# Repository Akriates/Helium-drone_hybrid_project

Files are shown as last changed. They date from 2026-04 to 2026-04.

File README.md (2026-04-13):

# Helium-drone_hybrid_project

An internship project to develop a working prototype of a helium drone hybrid

---

## Project Overview

This project focuses on developing a hybrid aerial system designed for **sustained surveillance**. By combining the natural lift of a helium balloon with the controlled movement of a drone, the system aims to remain airborne for extended periods while still being able to navigate its environment.

The helium component provides passive lift, reducing the energy required to stay airborne and enabling longer operation compared to traditional drones. Motorized propulsion allows the system to reposition and maintain control when needed, while an onboard camera supports real-time observation.

This project primarily serves as an **experimental prototype** to evaluate the feasibility and effectiveness of such a hybrid system. It explores how well a helium-assisted platform can perform in practical scenarios, identifying both its advantages and limitations.

Overall, the work lays the groundwork for future improvements in long-duration aerial monitoring, system stability, and autonomous capabilities.

---

## System Architecture

The system is built around a distributed architecture where each component is responsible for a specific function:

* **Raspberry Pi 5** – Main processing unit, handles high-level control, ROS 2 communication, and future vision processing
* **Arduino Uno** – Controls servos and processes IMU data
* **Pixhawk 2.4.8** – Handles motor control and low-level flight stabilization

This separation allows the system to remain modular, making it easier to debug, upgrade, and expand in future iterations.

---

## Hardware

### Mechanical Structure

The parts within this folder correspond to the **final tested prototype** used during system validation. This includes the full mechanical structure that supports the propulsion system, electronics, and camera assembly.

While this design was functional, it should be considered an **early iteration**. A redesign is recommended to improve:

* Wiring integration and routing
* Structural strength and weight distribution
* Ease of assembly and maintenance
* Mounting solutions for electronics and sensors

### Full Assembly

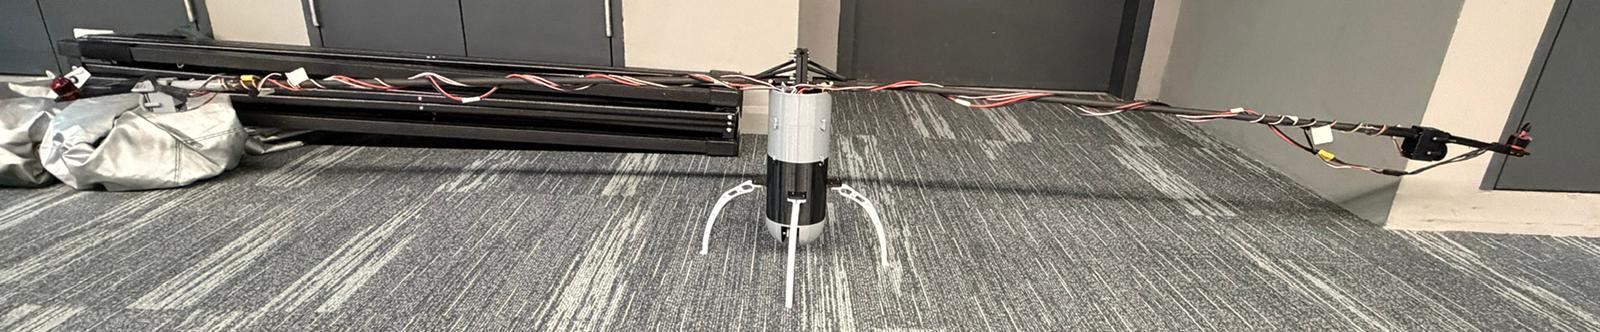
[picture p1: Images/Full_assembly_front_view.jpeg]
Full Assembly

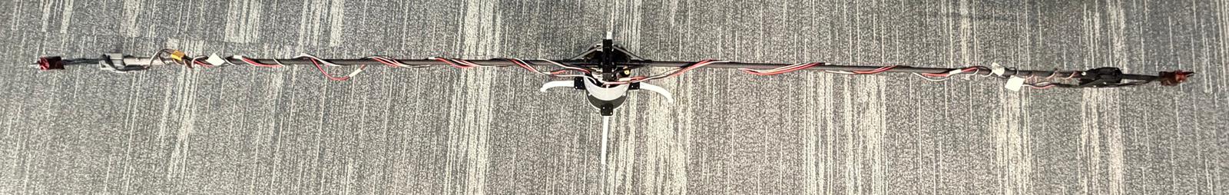
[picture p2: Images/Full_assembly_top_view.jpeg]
Full Assembly

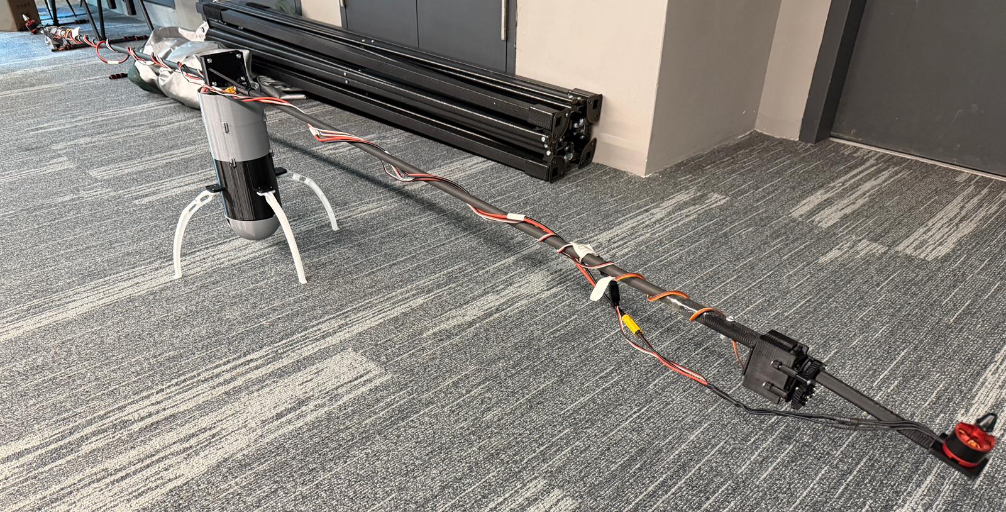
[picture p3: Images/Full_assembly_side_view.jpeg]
Full Assembly


---

### Electronics

#### Components Used

**Control Systems**

* Raspberry Pi 5
* Arduino Uno
* Pixhawk 2.4.8

**Actuation**

* MG996R Servos
* A2212 Brushless Motors
* Electronic Speed Controllers (ESCs)

**Sensing**

* MPU9250 IMU

**Wiring and Power**

* Jumper wires (male-to-male, male-to-female)
* Servo extension cables
* Custom XT60 power cables (~1m)
* Custom power distribution wiring
* Additional connection wires

#### Wiring Layout

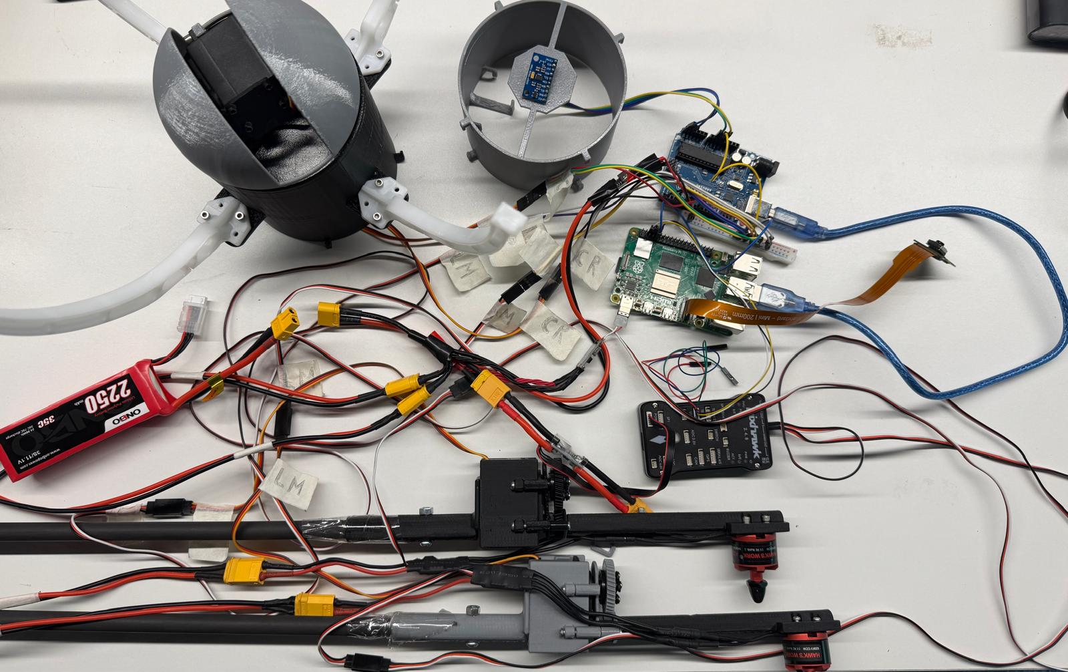
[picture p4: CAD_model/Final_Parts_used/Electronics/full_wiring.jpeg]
Full Wiring

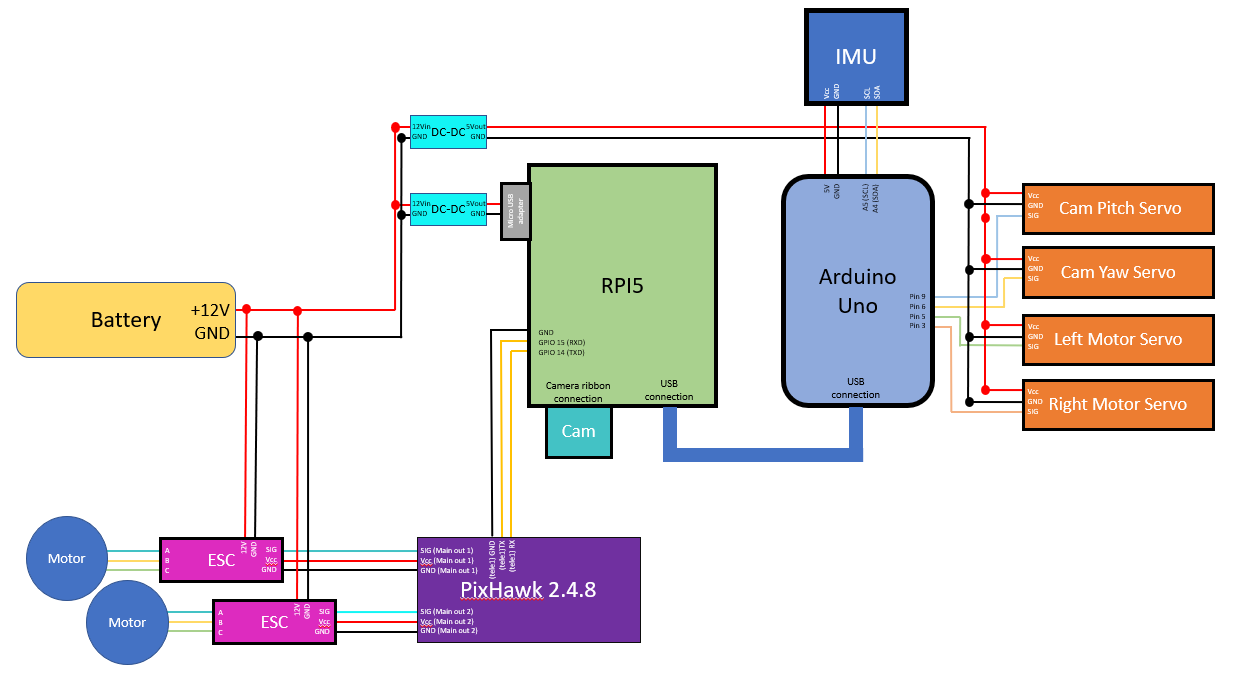
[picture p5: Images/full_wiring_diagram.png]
Full Wiring


#### Design Considerations

* Avoid powering servos directly from microcontroller 5V rails
* Improve cable management and routing
* Replace temporary jumper wires with secure connectors
* Use dedicated power distribution solutions
* Integrate wiring paths into the mechanical design

---

## Software

The system software is primarily built on **ROS 2**, enabling communication between different components of the system.

### Key Features

* Serial communication between Raspberry Pi and Arduino for servo control and IMU data
* MAVLink communication between Raspberry Pi and Pixhawk for motor control
* Teleoperation nodes for movement and camera control
* Real-time sensor feedback integration

The software is designed to be modular, allowing future integration of computer vision and autonomous control systems.

---

## Results and Testing

The prototype successfully demonstrated:

* Basic controlled movement using motor tilt mechanisms
* Stable communication between Raspberry Pi, Arduino, and Pixhawk
* Real-time IMU data acquisition
* Functional camera positioning system

The system validated the core concept of combining helium lift with drone propulsion for extended operation.

---

## Limitations

* Limited stability in dynamic environments
* No true position hold (IMU-only stabilization)
* Wiring complexity affects reliability
* Mechanical structure not optimized for long-term use

---

## Future Work

Future improvements will focus on:

* Improved mechanical design with integrated wiring channels
* Advanced stabilization algorithms
* Integration of additional sensors (e.g. GPS, barometer)
* Computer vision for tracking and autonomous navigation
* More efficient power distribution system

---

## Acknowledgements

This project was developed as part of an internship program, serving as a proof-of-concept for hybrid aerial surveillance systems.

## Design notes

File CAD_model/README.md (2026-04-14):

## CAD Models

This folder contains the different model versions developed throughout the project. These models represent multiple design iterations created from repeated testing and refinement.

- **Full Model (Version 1)**  
  This is the first and most complete design, created as a reverse-engineered approximation of an existing helium drone product. It represents the best attempt at replicating a functional system based on available observations and understanding.

- **Final Parts Configuration**  
  This version focuses primarily on the **electronics packaging and integration**, ensuring that all components could be physically mounted and operated together for a self-contained test setup.

- **Version 2 (Conceptual Design)**  
  This is a theoretical redesign developed after insights gained from building and testing the initial prototype. It reflects improvements in structure, layout, and overall system considerations.

Overall, these models document the design evolution of the project, from initial replication to more informed and refined concepts.

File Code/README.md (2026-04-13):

# System Overview

This system is built around a Raspberry Pi 5 acting as the main controller. It interfaces with an Arduino Uno over USB serial for servo control and IMU data, and a Pixhawk 2.4.8 over UART (MAVLink) for motor control.

The Raspberry Pi sends commands to control motor tilt and camera servos, receives real-time orientation data (roll, pitch, yaw), and manages motor arming and throttle through the Pixhawk.

ROS 2 is used to structure the system, with nodes handling serial communication, MAVLink control, and data publishing. This setup provides a foundation for teleoperation and future extensions such as computer vision and autonomous control.

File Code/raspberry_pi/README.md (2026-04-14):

# Raspberry Pi Control System (Arduino + Pixhawk + ROS 2)

This module runs on the **Raspberry Pi 5** and acts as the central control computer for the system. It manages communication with both the Arduino Uno (USB serial) for servo control and IMU data, and the Pixhawk 2.4.8 (UART via MAVLink) for motor control.

The Raspberry Pi is responsible for sending commands, receiving sensor data, and running ROS 2 nodes that coordinate the entire system.

---

## Core Responsibilities

The Raspberry Pi handles:

- Sending servo commands to the Arduino over USB serial
- Receiving and parsing IMU data from the Arduino
- Communicating with Pixhawk using MAVLink (pymavlink)
- Arming/disarming motors and sending RC override signals
- Running ROS 2 nodes for control and communication
- Acting as the platform for:
  - Teleoperation
  - Sensor processing
  - Future autonomy (CV, navigation)

---

## Hardware Connections

### Arduino (USB Serial)
- Device: /dev/ttyACM0 (may vary)
- Baud rate: 115200

### Pixhawk (UART)
- Device: /dev/ttyAMA0
- Baud rate: 57600
- Connection:
  - Pixhawk TX → Pi RX
  - Pixhawk RX → Pi TX
  - Shared GND

---

## Arduino Serial Communication

Commands are newline-terminated strings:

COMMAND,arg1,arg2,...

### Commands

Drive servos:
DRV,right,left

Camera servos:
CAM,rot,pitch

All servos:
ALL,right,left,rot,pitch

Ping:
PING

### Expected Responses

- ACK,DRV
- ACK,CAM
- ACK,ALL
- PONG
- ERR,BAD_DRV
- ERR,BAD_CAM
- ERR,BAD_ALL
- ERR,UNKNOWN_CMD

---

## IMU Data Stream

The Arduino continuously sends IMU data at ~20 Hz:

IMU,ax,ay,az,gx,gy,gz,mx,my,mz,roll,pitch,yaw

### Field Description

- ax, ay, az → acceleration (g)
- gx, gy, gz → angular velocity (deg/s)
- mx, my, mz → magnetometer (calibrated)
- roll, pitch, yaw → orientation (degrees)

---

## Python Serial Example

```python
import serial

ser = serial.Serial('/dev/ttyACM0', 115200, timeout=1)

ser.write(b'DRV,45,135\n')

while True:
    line = ser.readline().decode().strip()
    if line:
        print(line)
```

---

## Pixhawk Communication (MAVLink)

```python
from pymavlink import mavutil

master = mavutil.mavlink_connection('/dev/ttyAMA0', baud=57600)
master.wait_heartbeat()
print("Connected to Pixhawk")
```

---

## Motor Control

Arm motors:

```python
master.arducopter_arm()
master.motors_armed_wait()
```

Disarm motors:

```python
master.arducopter_disarm()
```

---

## RC Override Example

```python
master.mav.rc_channels_override_send(
    master.target_system,
    master.target_component,
    1500, 1500, 1500, 1500,
    0, 0, 0, 0
)
```

Notes:
- Channel 3 = throttle
- 1000 = minimum
- 1500 = neutral
- 2000 = maximum

---

## ROS 2 Integration (Jazzy)

### Topics

Subscribed:
- /servo_drive_cmd → [right, left]
- /servo_camera_cmd → [rot, pitch]

Published:
- /arduino_imu → sensor_msgs/msg/Imu

---

## Node Responsibilities

Serial Bridge Node:
- Opens /dev/ttyACM0
- Sends DRV / CAM commands
- Reads IMU data
- Publishes IMU messages

MAVLink Node:
- Connects to Pixhawk
- Arms/disarms motors
- Sends RC override commands

---

## Launch File Example

```python
from launch import LaunchDescription
from launch_ros.actions import Node

def generate_launch_description():
    return LaunchDescription([
        Node(
            package='helium_arduino_interface',
            executable='serial_bridge',
            name='arduino_serial'
        ),
        Node(
            package='helium_mav_control',
            executable='mav_motor_controller',
            name='pixhawk_control'
        ),
    ])
```

---

## Teleoperation Example

Drive mapping:

- w → forward
- s → backward
- a → left
- d → right
- x → neutral

Camera:
- rotation centered at 90°
- pitch centered at 45°
- incremental control

---

## Startup Behavior

When the Arduino is ready, it sends:

READY

The Raspberry Pi should wait for this before sending commands.

---

## Main Runtime Behavior

The Raspberry Pi continuously:

1. Reads serial input from Arduino
2. Parses IMU and ACK messages
3. Sends servo commands when needed
4. Sends MAVLink commands to Pixhawk
5. Publishes data to ROS 2 topics

---

## Important Notes

- Do not run MAVProxy and ROS node on /dev/ttyAMA0 at the same time
- Only one process should access each serial port
- Always send newline (\n) with commands
- Disarm is the safest way to stop motors
- Ensure correct UART wiring (TX ↔ RX)

---

## Limitations

- No automatic reconnect
- No command retry system
- No synchronization between IMU and Pixhawk data
- No position hold (IMU-only system)
- No Pi-side failsafe

---

## Summary

The Raspberry Pi acts as the central control layer, interfacing with both the Arduino and Pixhawk. It sends actuator commands, receives IMU data, and runs ROS 2 nodes that enable system control, integration, and future expansion.

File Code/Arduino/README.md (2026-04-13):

# Arduino Servo + IMU Firmware (Arduino Uno)

This firmware runs on an **Arduino Uno** and provides a combined interface for **servo control** and **MPU9250 IMU sensing**. It exposes a simple **USB serial protocol** so an external system (Raspberry Pi) can send servo commands while receiving real-time IMU data. The code handles low-level hardware control, sensor fusion (roll, pitch, yaw), and continuous telemetry streaming.

The Arduino is connected to the Raspberry Pi via **USB serial (115200 baud)**.

---

## Features

- Control of **4 servos**
  - Right motor tilt
  - Left motor tilt
  - Camera rotation (pan)
  - Camera pitch (tilt)
- Reads **MPU9250 IMU (Accel + Gyro + Magnetometer)**
- Computes **roll, pitch, yaw** using a complementary filter
- Performs **magnetometer calibration at startup**
- Streams IMU data at **20 Hz**
- Supports a simple **serial command protocol**
- Uses **safe startup servo positions**

---

## Hardware Configuration

### Servos
| Function | Pin |
|---|-----|
| Right Motor Tilt | 3 |
| Left Motor Tilt | 5 |
| Camera Rotation | 6 |
| Camera Pitch | 9 |

### IMU
- Sensor: **MPU9250 + AK8963 magnetometer**
- Interface: **I2C (Wire library)**
- Addresses:
  - MPU9250: `0x68`
  - Magnetometer: `0x0C`

---

## Servo Behaviour

- Default startup positions:
  - Right motor: `90°`
  - Left motor: `90°`
  - Camera rotation: `90°`
  - Camera pitch: `45°`

- Angle limits:
  - General servos: `0° – 180°`
  - Camera pitch: `0° – 90°` (hardware constrained)

- Custom calibrated pulse widths:
  ```cpp
  servoRightMotor.attach(pin, 450, 2600);
  servoLeftMotor.attach(pin, 500, 2550);
  servoCamRot.attach(pin, 500, 2500);
  servoCamPitch.attach(pin, 500, 2500);

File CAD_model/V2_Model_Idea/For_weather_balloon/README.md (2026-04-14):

This version will be for working with the weather balloon for future testing before investing in a full custom frame and balloon

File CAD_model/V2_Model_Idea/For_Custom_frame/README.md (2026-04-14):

This version is just the new frame design based on what I learnt and inspiration after designing the first version

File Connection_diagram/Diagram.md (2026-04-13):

The full wiring diagram as a drawing:

Full Wiring

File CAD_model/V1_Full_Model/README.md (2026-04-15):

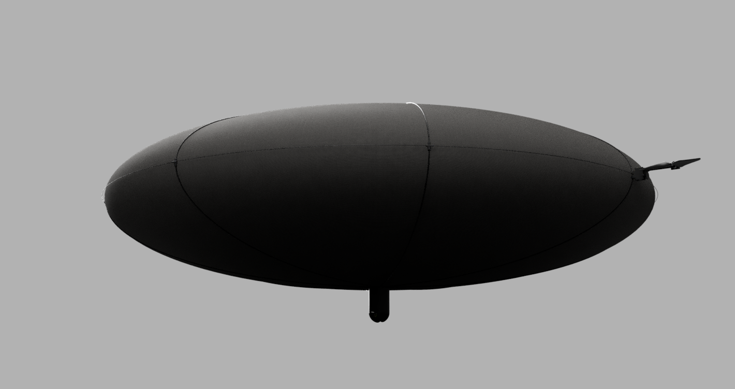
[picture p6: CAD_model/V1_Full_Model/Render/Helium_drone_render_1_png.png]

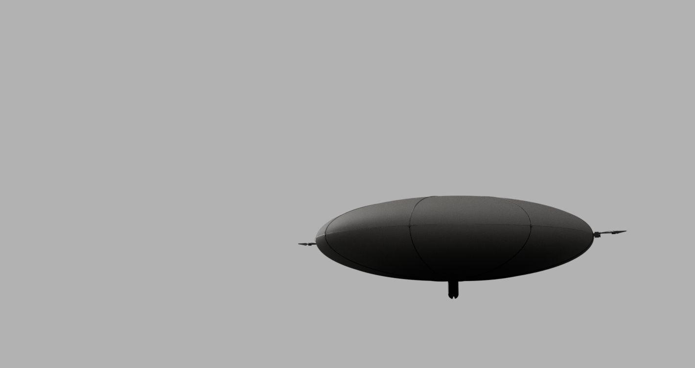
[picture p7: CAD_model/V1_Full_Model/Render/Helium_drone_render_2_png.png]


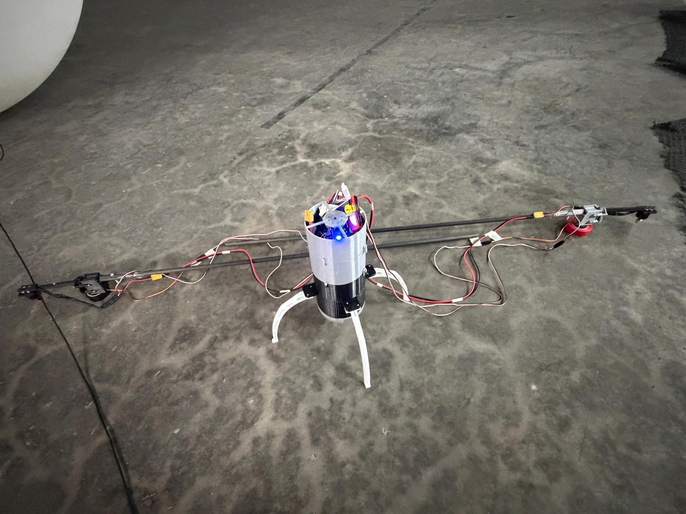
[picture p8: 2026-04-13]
Images/Electronics_Pack_and_motors.jpeg

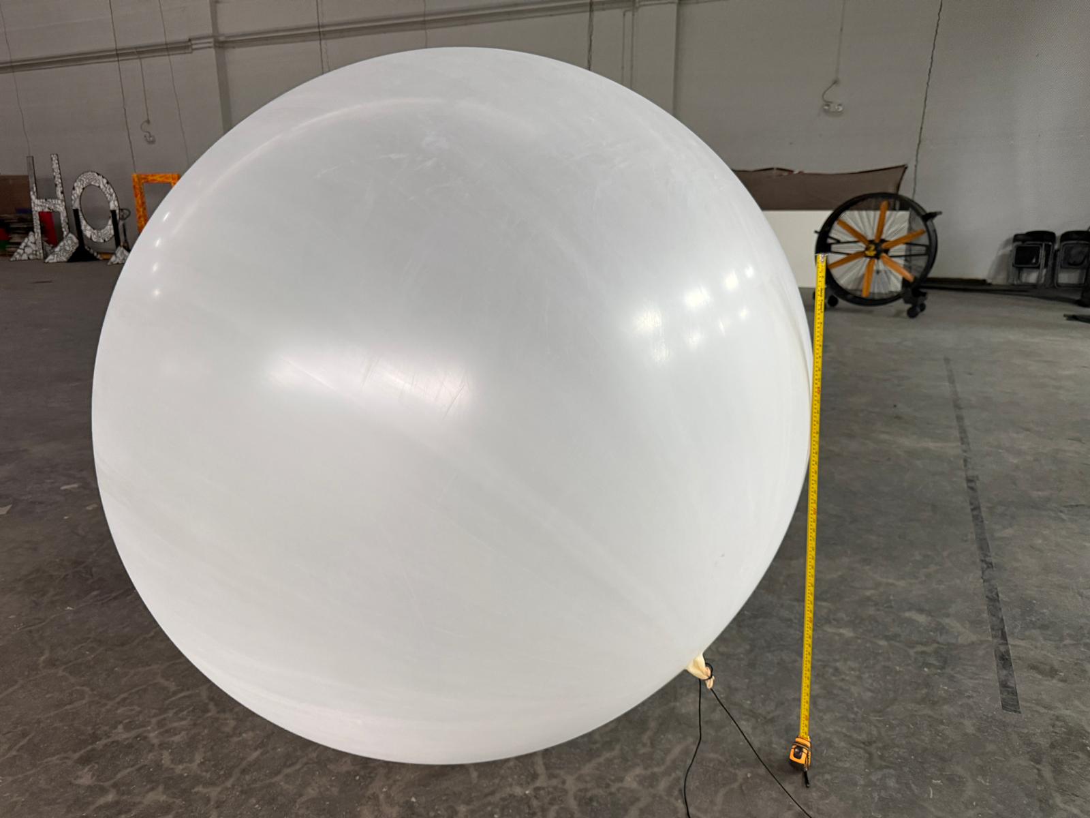
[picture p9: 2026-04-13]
Images/Half_blown_up_Weather_Balloon.jpeg

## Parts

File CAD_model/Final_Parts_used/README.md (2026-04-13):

## Model

The parts within this folder correspond to the **final tested prototype** used during system validation. This includes the full mechanical structure that supports the propulsion system, electronics, and camera assembly.

While this design was functional and enabled successful testing, it should be considered an **early iteration**. A redesign is recommended to better account for practical considerations such as:
- Wiring integration and routing  
- Structural strength and weight distribution  
- Ease of assembly and maintenance  
- Mounting points for electronics and sensors  

---

### Full Assembly

The complete assembled prototype is shown below:

Full Assembly

---

## Electronics

The following components were used in the final prototype to achieve control, sensing, and actuation.

### Components Used

**Control Systems**
- Raspberry Pi 5 (main processor, ROS 2 control)
- Arduino Uno (servo control and IMU processing)
- Pixhawk 2.4.8 (motor control)

**Actuation**
- MG996R Servos (motor tilting and camera gimbal)
- A2212 Brushless Motors
- Electronic Speed Controllers (ESCs)

**Sensing**
- MPU9250 IMU

**Wiring and Power**
- Jumper wires (male-to-male, male-to-female)
- Servo extension cables  
- Custom XT60 cables (~1m, male-to-female)  
- Custom power distribution wiring  
- Various additional connection wires  

---

### Wiring Layout

The full wiring configuration is shown below:

Full Wiring

---

### Design Considerations

The current electronics setup is functional but not optimized. Future iterations should focus on:

- Proper cable management and routing  
- Dedicated power distribution (avoid powering servos from microcontroller rails)  
- Reducing reliance on temporary jumper connections  
- Improving connector reliability  
- Designing the mechanical structure with integrated wiring paths

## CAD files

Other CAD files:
CAD_model/Final_Parts_used/2mm pin.f3d
CAD_model/Final_Parts_used/3mm pin.f3d
CAD_model/Final_Parts_used/Bottom box.f3d
CAD_model/Final_Parts_used/Top box.f3d
CAD_model/Final_Parts_used/clamp side 2.f3d
CAD_model/Final_Parts_used/direct cam mount.f3d
CAD_model/Final_Parts_used/pitch mount.f3d
CAD_model/Final_Parts_used/pixhawk stand.f3d
CAD_model/Final_Parts_used/rotating mount.f3d

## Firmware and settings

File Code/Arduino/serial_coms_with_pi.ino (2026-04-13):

#include <Wire.h>
#include <math.h>
#include <Servo.h>

// =========================
// Servo pins
// =========================
#define SERVO_RIGHT_MOTOR_PIN 3
#define SERVO_LEFT_MOTOR_PIN 5
#define SERVO_CAM_ROT_PIN 6
#define SERVO_CAM_PITCH_PIN 9

Servo servoRightMotor;
Servo servoLeftMotor;
Servo servoCamRot;
Servo servoCamPitch;

// =========================
// MPU9250 / AK8963
// =========================
#define MPU_ADDR     0x68
#define AK8963_ADDR  0x0C

// MPU registers
#define PWR_MGMT_1    0x6B
#define ACCEL_CONFIG  0x1C
#define GYRO_CONFIG   0x1B
#define ACCEL_XOUT_H  0x3B
#define INT_PIN_CFG   0x37

// Magnetometer registers
#define AK8963_ST1    0x02
#define AK8963_XOUT_L 0x03
#define AK8963_CNTL1  0x0A

int16_t accelX, accelY, accelZ;
int16_t gyroX, gyroY, gyroZ;
int16_t magX, magY, magZ;

const float ACCEL_SCALE = 16384.0;   // +-2g
const float GYRO_SCALE  = 131.0;     // +-250 deg/s

float roll = 0.0;
float pitch = 0.0;
float yaw = 0.0;

unsigned long prevTime = 0;
const float alpha = 0.98;

// Magnetometer calibration offsets
float magOffsetX = 0;
float magOffsetY = 0;
float magOffsetZ = 0;

// Optional scale correction
float magScaleX = 1.0;
float magScaleY = 1.0;
float magScaleZ = 1.0;

// =========================
// Servo command state
// =========================
int rightMotorAngle = 90;
int leftMotorAngle = 90;
int camRotAngle = 90;
int camPitchAngle = 45;

// Serial input buffer
String inputLine = "";

// IMU streaming rate
unsigned long lastImuSend = 0;
const unsigned long imuPeriodMs = 50;   // 20 Hz

// =========================
// I2C helpers
// =========================
void writeByte(uint8_t address, uint8_t reg, uint8_t data) {
  Wire.beginTransmission(address);
  Wire.write(reg);
  Wire.write(data);
  Wire.endTransmission();
}

uint8_t readByte(uint8_t address, uint8_t reg) {
  Wire.beginTransmission(address);
  Wire.write(reg);
  Wire.endTransmission(false);
  Wire.requestFrom(address, (uint8_t)1);

  if (Wire.available()) return Wire.read();
  return 0xFF;
}

void readBytes(uint8_t address, uint8_t reg, uint8_t count, uint8_t *dest) {
  Wire.beginTransmission(address);
  Wire.write(reg);
  Wire.endTransmission(false);
  Wire.requestFrom(address, count);

  uint8_t i = 0;
  while (Wire.available() && i < count) {
    dest[i++] = Wire.read();
  }
}

// =========================
// IMU setup
// =========================
void setupMPU() {
  writeByte(MPU_ADDR, PWR_MGMT_1, 0x00);
  delay(100);

  writeByte(MPU_ADDR, ACCEL_CONFIG, 0x00); // +-2g
  writeByte(MPU_ADDR, GYRO_CONFIG, 0x00);  // +-250 dps
  delay(100);
}

void setupMag() {
  writeByte(MPU_ADDR, INT_PIN_CFG, 0x02); // bypass mode
  delay(10);

  writeByte(AK8963_ADDR, AK8963_CNTL1, 0x00);
  delay(10);

  writeByte(AK8963_ADDR, AK8963_CNTL1, 0x16); // continuous mode 2, 16-bit
  delay(10);
}

// =========================
// IMU read functions
// =========================
void readAccelGyro() {
  uint8_t rawData[14];
  readBytes(MPU_ADDR, ACCEL_XOUT_H, 14, rawData);

  accelX = ((int16_t)rawData[0] << 8) | rawData[1];
  accelY = ((int16_t)rawData[2] << 8) | rawData[3];
  accelZ = ((int16_t)rawData[4] << 8) | rawData[5];

  gyroX = ((int16_t)rawData[8] << 8) | rawData[9];
  gyroY = ((int16_t)rawData[10] << 8) | rawData[11];
  gyroZ = ((int16_t)rawData[12] << 8) | rawData[13];
}

bool readMag() {
  uint8_t st1 = readByte(AK8963_ADDR, AK8963_ST1);
  if (!(st1 & 0x01)) return false;

  uint8_t magData[7];
  readBytes(AK8963_ADDR, AK8963_XOUT_L, 7, magData);

  magX = ((int16_t)magData[1] << 8) | magData[0];
  magY = ((int16_t)magData[3] << 8) | magData[2];
  magZ = ((int16_t)magData[5] << 8) | magData[4];

  return true;
}

void calibrateMagnetometer() {
  Serial.println("INFO,Mag calibration starting");
  Serial.println("INFO,Move IMU in all directions for 15 seconds");

  int16_t minX = 32767, minY = 32767, minZ = 32767;
  int16_t maxX = -32768, maxY = -32768, maxZ = -32768;

  unsigned long startTime = millis();

  while (millis() - startTime < 15000) {
    if (readMag()) {
      if (magX < minX) minX = magX;
      if (magY < minY) minY = magY;
      if (magZ < minZ) minZ = magZ;

      if (magX > maxX) maxX = magX;
      if (magY > maxY) maxY = magY;
      if (magZ > maxZ) maxZ = magZ;
    }

    delay(50);
  }

  magOffsetX = (maxX + minX) / 2.0;
  magOffsetY = (maxY + minY) / 2.0;
  magOffsetZ = (maxZ + minZ) / 2.0;

  float rangeX = (maxX - minX) / 2.0;
  float rangeY = (maxY - minY) / 2.0;
  float rangeZ = (maxZ - minZ) / 2.0;

  float avgRange = (rangeX + rangeY + rangeZ) / 3.0;

  if (rangeX != 0) magScaleX = avgRange / rangeX;
  if (rangeY != 0) magScaleY = avgRange / rangeY;
  if (rangeZ != 0) magScaleZ = avgRange / rangeZ;

  Serial.print("INFO,Mag offsets,");
  Serial.print(magOffsetX); Serial.print(",");
  Serial.print(magOffsetY); Serial.print(",");
  Serial.println(magOffsetZ);

  Serial.print("INFO,Mag scales,");
  Serial.print(magScaleX, 3); Serial.print(",");
  Serial.print(magScaleY, 3); Serial.print(",");
  Serial.println(magScaleZ, 3);

  Serial.println("INFO,Calibration complete");
}

// =========================
// Angle helpers
// =========================
int clampAngle(int val, int minVal = 0, int maxVal = 180) {
  if (val < minVal) return minVal;
  if (val > maxVal) return maxVal;
  return val;
}

int clampCamPitch(int val) {
  if (val < 0) return 0;
  if (val > 90) return 90;
  return val;
}

void applyServoPositions() {
  servoRightMotor.write(rightMotorAngle);
  servoLeftMotor.write(leftMotorAngle);
  servoCamRot.write(camRotAngle);
  servoCamPitch.write(camPitchAngle);
}

void setDriveServos(int rightDeg, int leftDeg) {
  rightMotorAngle = clampAngle(rightDeg);
  leftMotorAngle = clampAngle(leftDeg);
  applyServoPositions();
}

void setCameraServos(int rotDeg, int pitchDeg) {
  camRotAngle = clampAngle(rotDeg);
  camPitchAngle = clampCamPitch(pitchDeg);
  applyServoPositions();
}

void setAllServos(int rightDeg, int leftDeg, int rotDeg, int pitchDeg) {
  rightMotorAngle = clampAngle(rightDeg);
  leftMotorAngle = clampAngle(leftDeg);
  camRotAngle = clampAngle(rotDeg);
  camPitchAngle = clampCamPitch(pitchDeg);
  applyServoPositions();
}

// =========================
// Serial command parser
// =========================
void processCommand(String line) {
  line.trim();
  if (line.length() == 0) return;

  if (line.startsWith("DRV,")) {
    int firstComma = line.indexOf(',');
    int secondComma = line.indexOf(',', firstComma + 1);

    if (secondComma > 0) {
      int s1 = line.substring(firstComma + 1, secondComma).toInt();
      int s2 = line.substring(secondComma + 1).toInt();
      setDriveServos(s1, s2);
      Serial.println("ACK,DRV");
    } else {
      Serial.println("ERR,BAD_DRV");
    }
    return;
  }

  if (line.startsWith("CAM,")) {
    int firstComma = line.indexOf(',');
    int secondComma = line.indexOf(',', firstComma + 1);

    if (secondComma > 0) {
      int rot = line.substring(firstComma + 1, secondComma).toInt();
      int pit = line.substring(secondComma + 1).toInt();
      setCameraServos(rot, pit);
      Serial.println("ACK,CAM");
    } else {
      Serial.println("ERR,BAD_CAM");
    }
    return;
  }

  if (line.startsWith("ALL,")) {
    int c1 = line.indexOf(',');
    int c2 = line.indexOf(',', c1 + 1);
    int c3 = line.indexOf(',', c2 + 1);
    int c4 = line.indexOf(',', c3 + 1);

    if (c2 > 0 && c3 > 0 && c4 > 0) {
      int s1 = line.substring(c1 + 1, c2).toInt();
      int s2 = line.substring(c2 + 1, c3).toInt();
      int rot = line.substring(c3 + 1, c4).toInt();
      int pit = line.substring(c4 + 1).toInt();
      setAllServos(s1, s2, rot, pit);
      Serial.println("ACK,ALL");
    } else {
      Serial.println("ERR,BAD_ALL");
    }
    return;
  }

  if (line == "PING") {
    Serial.println("PONG");
    return;
  }

  Serial.println("ERR,UNKNOWN_CMD");
}

void readSerialCommands() {
  while (Serial.available() > 0) {
    char c = Serial.read();

    if (c == '\n') {
      processCommand(inputLine);
      inputLine = "";
    } else if (c != '\r') {
      inputLine += c;
    }
  }
}

// =========================
// IMU update and output
// =========================
void updateIMU() {
  readAccelGyro();

  unsigned long currentTime = millis();
  float dt = (currentTime - prevTime) / 1000.0;
  prevTime = currentTime;

  if (dt <= 0) dt = 0.01;

  float ax = accelX / ACCEL_SCALE;
  float ay = accelY / ACCEL_SCALE;
  float az = accelZ / ACCEL_SCALE;

  float gx = gyroX / GYRO_SCALE;
  float gy = gyroY / GYRO_SCALE;
  float gz = gyroZ / GYRO_SCALE;

  float accelRoll  = atan2(ay, az) * 180.0 / PI;
  float accelPitch = atan2(-ax, sqrt(ay * ay + az * az)) * 180.0 / PI;

  roll  = alpha * (roll  + gx * dt) + (1.0 - alpha) * accelRoll;
  pitch = alpha * (pitch + gy * dt) + (1.0 - alpha) * accelPitch;

  if (readMag()) {
    float mx = (magX - magOffsetX) * magScaleX;
    float my = (magY - magOffsetY) * magScaleY;
    float mz = (magZ - magOffsetZ) * magScaleZ;

    float rollRad = roll * PI / 180.0;
    float pitchRad = pitch * PI / 180.0;

    float Xh = mx * cos(pitchRad) + mz * sin(pitchRad);
    float Yh = mx * sin(rollRad) * sin(pitchRad) + my * cos(rollRad) - mz * sin(rollRad) * cos(pitchRad);

    yaw = atan2(-Yh, Xh) * 180.0 / PI;
    if (yaw < 0) yaw += 360.0;
  }
}

void sendIMU() {
  float ax = accelX / ACCEL_SCALE;
  float ay = accelY / ACCEL_SCALE;
  float az = accelZ / ACCEL_SCALE;

  float gx = gyroX / GYRO_SCALE;
  float gy = gyroY / GYRO_SCALE;
  float gz = gyroZ / GYRO_SCALE;

  float mx = (magX - magOffsetX) * magScaleX;
  float my = (magY - magOffsetY) * magScaleY;
  float mz = (magZ - magOffsetZ) * magScaleZ;

  Serial.print("IMU,");
  Serial.print(ax, 3); Serial.print(",");
  Serial.print(ay, 3); Serial.print(",");
  Serial.print(az, 3); Serial.print(",");
  Serial.print(gx, 3); Serial.print(",");
  Serial.print(gy, 3); Serial.print(",");
  Serial.print(gz, 3); Serial.print(",");
  Serial.print(mx, 3); Serial.print(",");
  Serial.print(my, 3); Serial.print(",");
  Serial.print(mz, 3); Serial.print(",");
  Serial.print(roll, 2); Serial.print(",");
  Serial.print(pitch, 2); Serial.print(",");
  Serial.println(yaw, 2);
}

// =========================
// Setup / Loop
// =========================
void setup() {
  Wire.begin();
  Serial.begin(115200);
  delay(1000);

  // Final calibrated servo pulse widths
  servoRightMotor.attach(SERVO_RIGHT_MOTOR_PIN, 450, 2600);
  servoLeftMotor.attach(SERVO_LEFT_MOTOR_PIN, 500, 2550);
  servoCamRot.attach(SERVO_CAM_ROT_PIN, 500, 2500);
  servoCamPitch.attach(SERVO_CAM_PITCH_PIN, 500, 2500);

  // Safe startup positions
  rightMotorAngle = 90;
  leftMotorAngle = 90;
  camRotAngle = 90;
  camPitchAngle = 45;
  applyServoPositions();

  setupMPU();
  setupMag();
  calibrateMagnetometer();

  prevTime = millis();

  Serial.println("READY");
}

void loop() {
  readSerialCommands();

  unsigned long now = millis();
  if (now - lastImuSend >= imuPeriodMs) {
    lastImuSend = now;
    updateIMU();
    sendIMU();
  }
}

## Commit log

2026-03-19 CAD Model V1
2026-04-13 Rename CAD model/Helium drone STEP CAD model.7z to CAD model/V1_Full_Model/Helium drone STEP CAD model.7z
2026-04-13 Rename CAD model/Helium drone STL CAD model.7z to CAD model/V1_Full_Model/Helium drone STL CAD model.7z
2026-04-13 Rename 2mm pin.f3d to 2mm pin.f3d
    [2mm pin.f3d]
2026-04-13 Rename 3mm pin.f3d to 3mm pin.f3d
    [3mm pin.f3d]
2026-04-13 Rename Bottom box.f3d to Bottom box.f3d
    [Bottom box.f3d]
2026-04-13 Rename Top box.f3d to Top box.f3d
    [Top box.f3d]
2026-04-13 Rename clamp side 2.f3d to clamp side 2.f3d
    [clamp side 2.f3d]
2026-04-13 Rename direct cam mount.f3d to direct cam mount.f3d
    [direct cam mount.f3d]
2026-04-13 Rename motor connector.f3d to motor connector.f3d
    [motor connector.f3d]
2026-04-13 Rename pitch mount.f3d to pitch mount.f3d
    [pitch mount.f3d]
2026-04-13 Rename pixhawk stand.f3d to pixhawk stand.f3d
    [pixhawk stand.f3d]
2026-04-13 Rename rotating mount.f3d to rotating mount.f3d
    [rotating mount.f3d]
2026-04-13 Rename Helium drone STEP CAD model.7z to Helium drone STEP CAD model.7z
2026-04-13 Rename Helium drone STL CAD model.7z to Helium drone STL CAD model.7z
